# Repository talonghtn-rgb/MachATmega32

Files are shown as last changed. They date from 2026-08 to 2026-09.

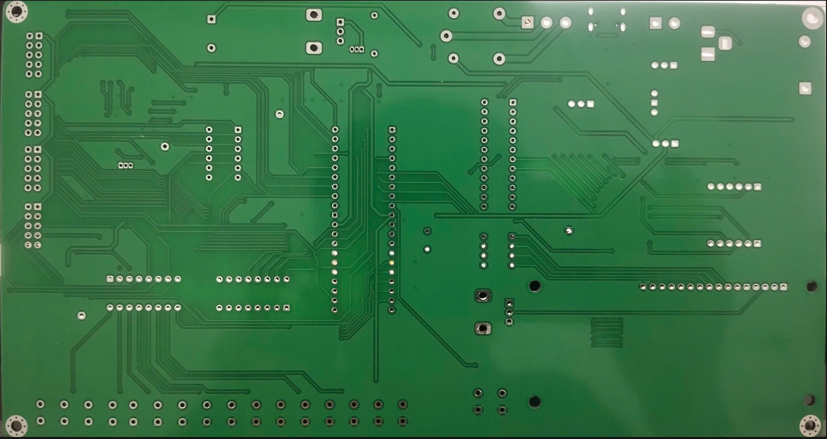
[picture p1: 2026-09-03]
Sp mặt sau.png

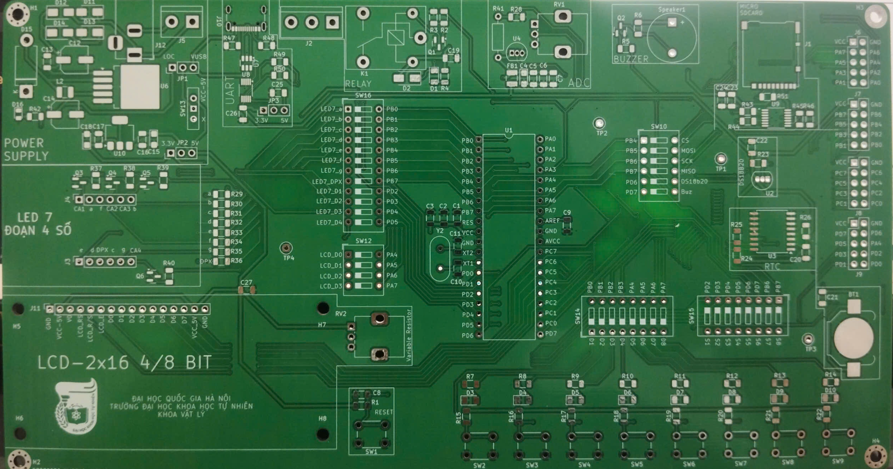
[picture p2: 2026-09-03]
Sp mặt trước.png

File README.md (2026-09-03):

# ATmega32 Embedded Learning Board

<h2 align="center">
  THIẾT KẾ VÀ CHẾ TẠO BO MẠCH LẬP TRÌNH NHÚNG DỰA TRÊN VI ĐIỀU KHIỂN AVR CHO MỤC ĐÍCH GIÁO DỤC
</h2>

<p align="center">
  <b>ATmega32 Embedded Training Board</b>
</p>

---

##  Giới thiệu

Đây là dự án thiết kế và chế tạo **bo mạch học tập lập trình nhúng sử dụng vi điều khiển ATmega32**, được xây dựng nhằm phục vụ việc học tập, thực hành và nghiên cứu các hệ thống nhúng.

Bo mạch tích hợp nhiều ngoại vi phổ biến, giúp sinh viên có thể thực hành lập trình vi điều khiển, giao tiếp với cảm biến, thiết bị hiển thị, bộ nhớ và các chuẩn giao tiếp thông dụng.

Toàn bộ sơ đồ nguyên lý và PCB của bo mạch được thiết kế bằng **KiCad**.

---

##  Mục tiêu

- Thiết kế một bo mạch học tập dựa trên vi điều khiển **ATmega32**.
- Tích hợp các ngoại vi thường sử dụng trong các bài thực hành vi điều khiển.
- Hỗ trợ nhiều chuẩn giao tiếp như UART, I2C, SPI và 1-Wire.
- Thiết kế PCB hoàn chỉnh bằng KiCad.
- Xây dựng nền tảng phần cứng phục vụ các bài thực hành lập trình nhúng.
- Kiểm thử từng chức năng của bo mạch trên phần cứng thực tế.

---

##  Vi điều khiển:  ATmega32

##  Các ngoại vi tích hợp

Bo mạch được thiết kế với các khối chức năng:

| Ngoại vi | Chức năng |
|---|---|
| LCD 16x2 | Hiển thị thông tin |
| LED 7 đoạn 4 số | Hiển thị số |
| LM35 | Đo nhiệt độ |
| DS18B20 | Cảm biến nhiệt độ |
| DS3231 | Đồng hồ thời gian thực |
| Relay | Điều khiển thiết bị |
| Micro SD Card | Lưu trữ dữ liệu |
| LED đơn | Hiển thị trạng thái |
| Button | Nhập tín hiệu số |
| Potentiometer | Tạo tín hiệu analog |
| LDR | Đo cường độ ánh sáng |
| CH340E | Giao tiếp USB-UART |

Các ngoại vi trên được tích hợp nhằm phục vụ nhiều bài thực hành về GPIO, ADC, UART, I2C, SPI, 1-Wire và điều khiển thiết bị.

---

##  Các chuẩn giao tiếp
UART,I2C,SPI,1-Wire

##  Thiết kế bằng KiCad

Project được thiết kế bằng **KiCad 9**.

Các file chính:

```text
ATmega32/
│
├── atmega32.kicad_pro       # KiCad Project
├── atmega32.kicad_sch       # Schematic
├── atmega32.kicad_pcb       # PCB Layout
│
├── aa.kicad_sym             # Custom Symbol Library
│
├── CR1220 SMD.pretty/       # Footprint Library
├── Micro.pretty/            # Footprint Library
├── SN74LVC125APWR.pretty/   # Footprint Library
│
├── fp-lib-table
├── sym-lib-table
└── Logo_hus.png
```

## Hình ảnh sản phẩm trong quá trình làm
## Ghi chú: Hình ảnh ở trên là bản đầu tiên làm, file ở trên đã sửa sau khi test các chức năng sửa những lỗi cho ra bản hoàn chỉnh nhất.

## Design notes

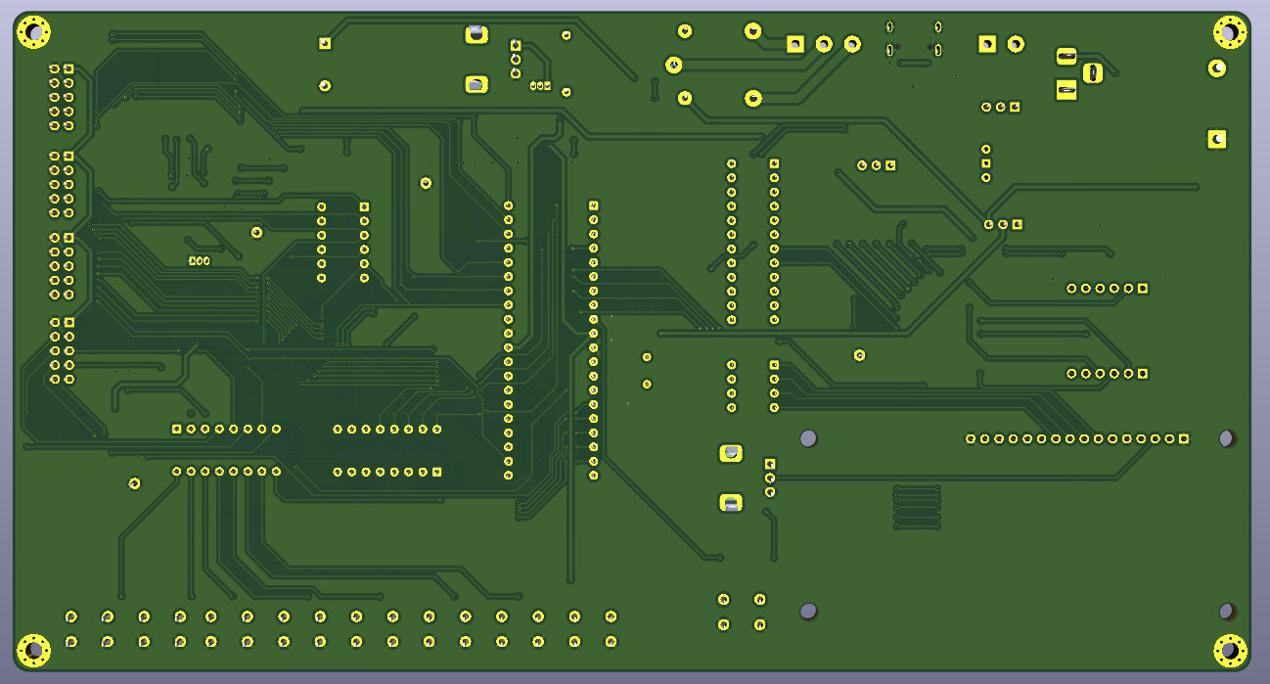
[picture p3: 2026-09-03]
Mach_ban3D_matsau.png

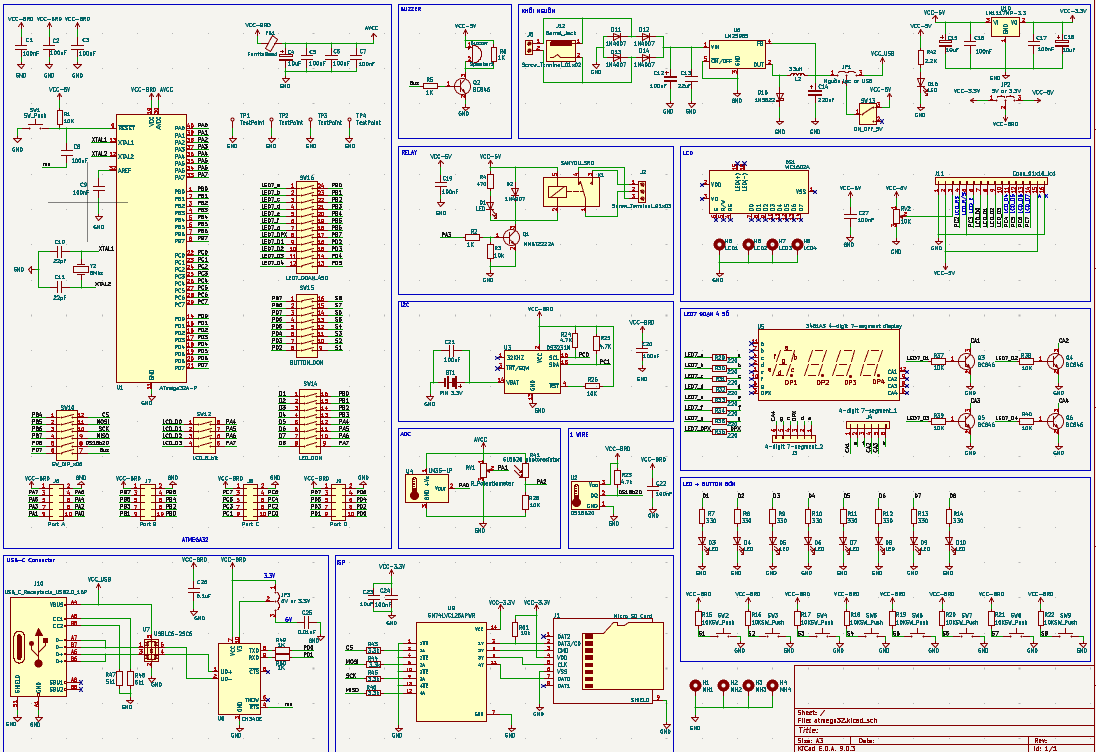
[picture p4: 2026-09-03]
machchinh_sche.png

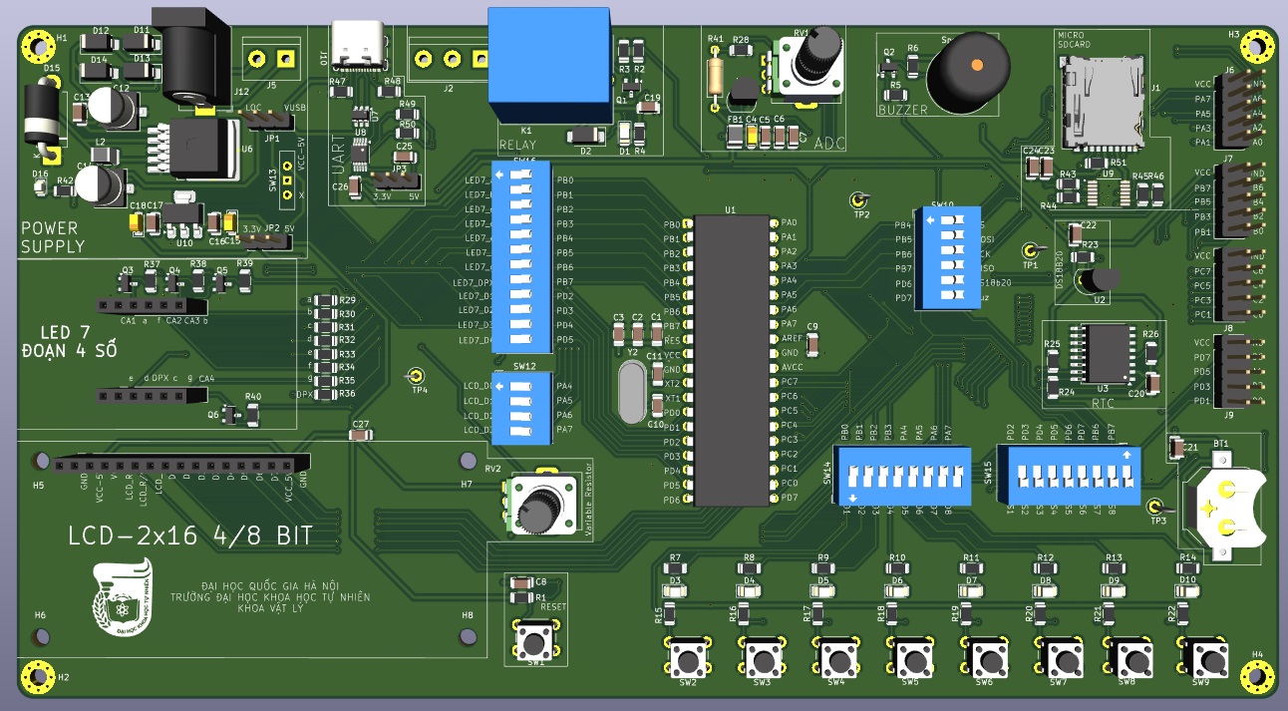
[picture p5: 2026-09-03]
Mach_ban3D_mattruoc.png

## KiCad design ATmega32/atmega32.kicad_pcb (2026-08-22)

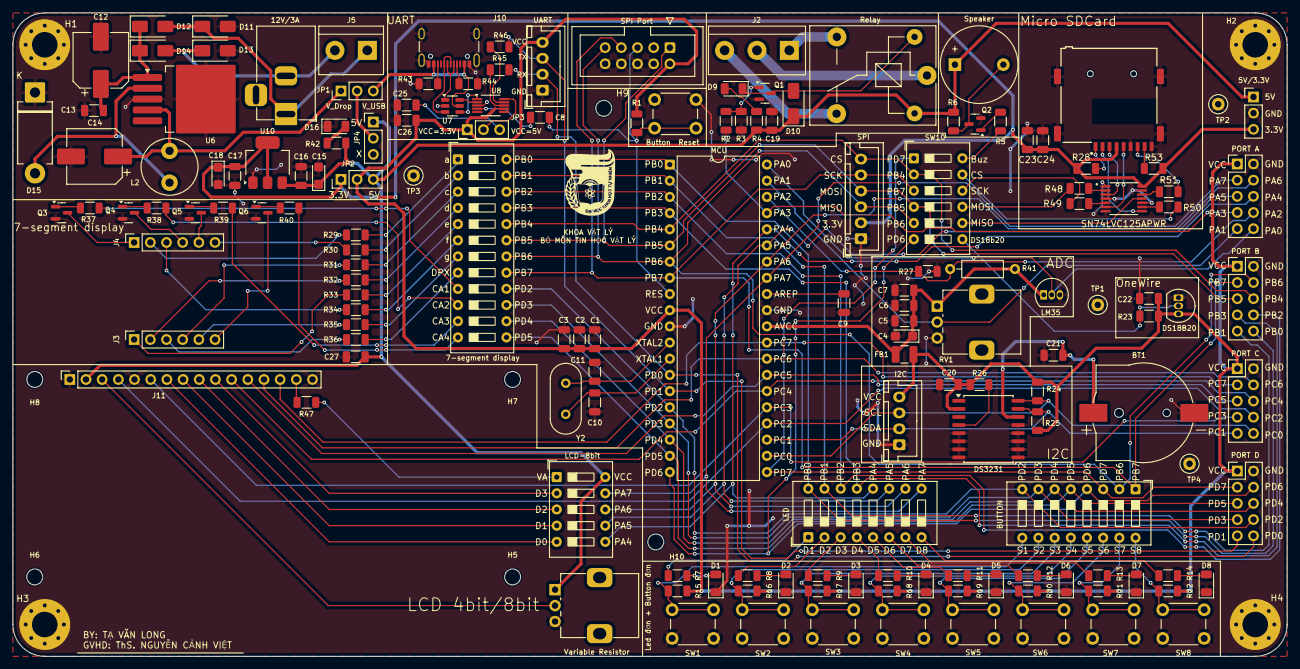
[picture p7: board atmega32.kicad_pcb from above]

Board: 2 copper layers, 200.0 x 101.0 mm, 168 parts (0 on the bottom side), 145 nets.

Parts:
5V/3.3V: 5V/3.3V; PinHeader_1x03_P2.54mm_Vertical
7-segment display: LED7_DOAN_4SO; SW_DIP_SPSTx12_Slide_9.78x32.66mm_W7.62mm_P2.54mm
12V/3A: Barrel_Jack; BarrelJack_Horizontal
 : LOGO
BT1: PIN; BatteryHolder_RSPRO_2378296_1x1220
BUTTON: BUTTON_DON; SW_DIP_SPSTx08_Slide_9.78x22.5mm_W7.62mm_P2.54mm
Button  Reset: SW_Push; SW_PUSH_6mm_H5mm
C1, C2, C3, C5, C6, C7, C8, C9, C16, C17, C19, C20, C21, C22, C24, C26, C27: 100nF; C_1206_3216Metric
C4, C15, C18: 10uF; CP_EIA-3216-18_Kemet-A
C10, C11: 22pF; C_1206_3216Metric
C12: 440uF/35V; CP_Elec_8x10.5
C13: 1000nF; C_1206_3216Metric
C14: 330uF/35V; CP_Elec_8x10.5
C23: 10uF; C_1206_3216Metric
C25: 10nF; C_1206_3216Metric
D1, D2, D3, D4, D5, D6, D7, D8, D9, D16: LED; LED_1206_3216Metric
D10, D11, D12, D13, D14: 1N4007; D_SMA
D15: 1N5822; D_DO-201AD_P12.70mm_Horizontal
DS18B20: DS18B20; TO-92_Inline
DS3231: DS3231M; SOIC-16W_7.5x10.3mm_P1.27mm
FB1: FerriteBead; L_1210_3225Metric
H1: MH1; MountingHole_4mm_Pad_Via
H2: MH2; MountingHole_4mm_Pad_Via
H3: MH3; MountingHole_4mm_Pad_Via
H4: MH4; MountingHole_4mm_Pad_Via
H5: LCD1; MountingHole_2.5mm
H6: LCD2; MountingHole_2.5mm
H7: LCD3; MountingHole_2.5mm
H8: LCD4; MountingHole_2.5mm
H9: MH5; MountingHole_2.5mm
H10: MH6; MountingHole_2.5mm
I2C: SCL/SDA; JST_XH_B4B-XH-A_1x04_P2.50mm_Vertical
J1: Micro_SD_Card; GCT_MEM2075
J2: Screw_Terminal_01x03; TerminalBlock_bornier-3_P5.08mm
J3: 4-digit 7-segment_2; PinSocket_1x06_P2.54mm_Vertical
J4: 4-digit 7-segment_1; PinSocket_1x06_P2.54mm_Vertical
J5: Screw_Terminal_01x02; TerminalBlock_bornier-2_P5.08mm
J10: USB_C_Receptacle_USB2.0_16P; USB_C_Receptacle_GCT_USB4105-xx-A_16P_TopMnt_Horizontal
J11: Conn_01x16_lcd; PinSocket_1x16_P2.54mm_Vertical
JP1: Nguồn lọc or USB; PinHeader_1x03_P2.54mm_Vertical
JP2, JP3: 5V or 3.3V; PinHeader_1x03_P2.54mm_Vertical
JP4: 5V or x; PinHeader_1x03_P2.54mm_Vertical
L2: 33uH; L_Radial_D8.7mm_P5.00mm_Fastron_07HCP
LCD-8bit: SW_LCD_8bit; SW_DIP_SPSTx05_Slide_9.78x14.88mm_W7.62mm_P2.54mm
LED: LED_DON; SW_DIP_SPSTx08_Slide_9.78x22.5mm_W7.62mm_P2.54mm
LM35: LM35-LP; TO-92_Inline
MCU: ATmega32A-P; DIP-40_W15.24mm
PORT A: Port A; PinHeader_2x05_P2.54mm_Vertical
PORT B: Port B; PinHeader_2x05_P2.54mm_Vertical
PORT C: Port C; PinHeader_2x05_P2.54mm_Vertical
PORT D: Port D; PinHeader_2x05_P2.54mm_Vertical
Q1: MMBT2222A; SOT-23
Q2, Q3, Q4, Q5, Q6: BC846; SOT-23
R1, R15, R16, R17, R18, R19, R20, R21, R22, R26, R27, R37, R38, R39, R40: 10K; R_1206_3216Metric
R2, R5, R6, R45, R46: 1K; R_1206_3216Metric
R3: 10k; R_1206_3216Metric
R4: 470; R_1206_3216Metric
R7, R8, R9, R10, R11, R12, R13, R14: 330; R_1206_3216Metric
R23: 4.7k; R_1206_3216Metric
R24, R25, R28, R53: 4.7K; R_1206_3216Metric
R29, R30, R31, R32, R33, R34, R35, R36, R47: 220; R_1206_3216Metric
R41: GL5528 photoresistor; R_Axial_DIN0207_L6.3mm_D2.5mm_P10.16mm_Horizontal
R42: 2.2K; R_1206_3216Metric
R43, R44: 5k1; R_1206_3216Metric
R48, R49, R50, R51: 3.3K; R_1206_3216Metric
RV1: R_Potentiometer; Potentiometer_Alps_RK09K_Single_Vertical
Relay: SANYOU_SRD; Relay_SPDT_SANYOU_SRD_Series_Form_C
SN74LVC125APWR: SN74LVC125APWR; SOP65P640X120-14N
SPI: SPI; JST_XH_B6B-XH-A_1x06_P2.50mm_Vertical
SPI Port: AVR-ISP-10; IDC-Header_2x05_P2.54mm_Vertical
SW1, SW2, SW3, SW4, SW5, SW6, SW7, SW8: SW_Push; SW_PUSH_6mm_H5mm
SW10: SW_DIP_x06; SW_DIP_SPSTx06_Slide_9.78x17.42mm_W7.62mm_P2.54mm
Speaker: Buzzer; Buzzer_12x9.5RM7.6
TP1, TP2, TP3, TP4: TestPoint; TestPoint_Loop_D2.50mm_Drill1.0mm
U6: LM2596S-ADJ; TO-263-5_TabPin3
U7: USBLC6-2SC6; SOT-23-6
U8: CH340E; MSOP-10_3x3mm_P0.5mm
U10: LM1117MP-3.3; SOT-223-3_TabPin2
UART: TX/RX; JST_XH_B4B-XH-A_1x04_P2.50mm_Vertical
Variable Resistor: 10K; Potentiometer_Alps_RK09K_Single_Vertical
Y2: 8Mhz; Crystal_HC49-U_Vertical

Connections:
/Buz: R5.1, SW10.12
/CA1: J4.1, Q3.3 (C)
/CA2: J4.4, Q4.3 (C)
/CA3: J4.5, Q5.3 (C)
/CA4: J3.6, Q6.3 (C)
/CD: J1.2 (DAT3/CD), SN74LVC125APWR.8 (3Y)
/CLK: J1.5 (CLK), SN74LVC125APWR.6 (2Y)
/CMD: J1.3 (CMD), SN74LVC125APWR.3 (1Y)
/CS: R50.2, SW10.11
/D0: J1.7 (DAT0), R51.2
/D1: LED.1, R7.2
/D2: LED.2, R8.2
/D3: LED.3, R9.2
/D4: LED.4, R10.2
/D5: LED.5, R11.2
/D6: LED.6, R12.2
/D7: LED.7, R13.2
/D8: LED.8, R14.2
/DPX: J3.3, R36.2
/DS18b20: DS18B20.2 (DQ), R23.1, SW10.7
/LCD_D0: J11.7, LCD-8bit.5
/LCD_D1: J11.8, LCD-8bit.4
/LCD_D2: J11.9, LCD-8bit.3
/LCD_D3: J11.10, LCD-8bit.2
/LED7_D1: 7-segment display.9, R37.1
/LED7_D2: 7-segment display.10, R38.1
/LED7_D3: 7-segment display.11, R39.1
/LED7_D4: 7-segment display.12, R40.1
/LED7_DPX: 7-segment display.8, R36.1
/LED7_a: 7-segment display.1, R29.1
/LED7_b: 7-segment display.2, R30.1
/LED7_c: 7-segment display.3, R31.1
/LED7_d: 7-segment display.4, R32.1
/LED7_e: 7-segment display.5, R33.1
/LED7_f: 7-segment display.6, R34.1
/LED7_g: 7-segment display.7, R35.1
/MISO: SN74LVC125APWR.11 (4Y), SW10.8
/MOSI: R48.2, SW10.9
/PA0: LM35.2 (V_{OUT}), MCU.40 (PA0), PORT A.10
/PA1: MCU.39 (PA1), PORT A.9, RV1.2
/PA2: MCU.38 (PA2), PORT A.8, R27.1, R41.2
/PA3: MCU.37 (PA3), PORT A.7, R2.1
/PA4: LCD-8bit.6, LED.12, MCU.36 (PA4), PORT A.6
/PA5: LCD-8bit.7, LED.11, MCU.35 (PA5), PORT A.5
/PA6: LCD-8bit.8, LED.10, MCU.34 (PA6), PORT A.4
/PA7: LCD-8bit.9, LED.9, MCU.33 (PA7), PORT A.3
/PB0: 7-segment display.24, LED.16, MCU.1 (PB0), PORT B.10
/PB1: 7-segment display.23, LED.15, MCU.2 (PB1), PORT B.9
/PB2: 7-segment display.22, LED.14, MCU.3 (PB2), PORT B.8
/PB3: 7-segment display.21, LED.13, MCU.4 (PB3), PORT B.7
/PB4: 7-segment display.20, MCU.5 (PB4), PORT B.6, SPI.6, SW10.2
/PB5: 7-segment display.19, MCU.6 (PB5), PORT B.5, SPI.4, SPI Port.1 (MOSI), SW10.4
/PB6: 7-segment display.18, BUTTON.2, MCU.7 (PB6), PORT B.4, SPI.3, SPI Port.9 (MISO), SW10.5
/PB7: 7-segment display.17, BUTTON.1, MCU.8 (PB7), PORT B.3, SPI.5, SPI Port.7 (SCK), SW10.3
/PC0: DS3231.16 (SCL), I2C.3, MCU.22 (PC0), PORT C.10, R24.1
/PC1: DS3231.15 (SDA), I2C.2, MCU.23 (PC1), PORT C.9, R25.1
/PC2: J11.4, MCU.24 (PC2), PORT C.8
/PC3: J11.6, MCU.25 (PC3), PORT C.7
/PC4: J11.11, MCU.26 (PC4), PORT C.6
/PC5: J11.12, MCU.27 (PC5), PORT C.5
/PC6: J11.13, MCU.28 (PC6), PORT C.4
/PC7: J11.14, MCU.29 (PC7), PORT C.3
/PD0: MCU.14 (PD0), PORT D.10, R45.2, UART.2
/PD1: MCU.15 (PD1), PORT D.9, R46.2, UART.3
/PD2: 7-segment display.16, BUTTON.8, MCU.16 (PD2), PORT D.8
/PD3: 7-segment display.15, BUTTON.7, MCU.17 (PD3), PORT D.7
/PD4: 7-segment display.14, BUTTON.6, MCU.18 (PD4), PORT D.6
/PD5: 7-segment display.13, BUTTON.5, MCU.19 (PD5), PORT D.5
/PD6: BUTTON.4, MCU.20 (PD6), PORT D.4, SW10.6
/PD7: BUTTON.3, MCU.21 (PD7), PORT D.3, SW10.1
/S1: BUTTON.9, R15.1, SW1.1
/S2: BUTTON.10, R16.1, SW2.1
/S3: BUTTON.11, R17.1, SW3.1
/S4: BUTTON.12, R18.1, SW4.1
/S5: BUTTON.13, R19.1, SW5.1
/S6: BUTTON.14, R20.1, SW6.1
/S7: BUTTON.15, R21.1, SW7.1
/S8: BUTTON.16, R22.1, SW8.1
/SCK: R49.2, SW10.10
/VA: LCD-8bit.1, R47.1
/a: J4.2, R29.2
/b: J4.6, R30.2
/c: J3.4, R31.2
/d: J3.2, R32.2
/e: J3.1, R33.2
/f: J4.3, R34.2
/g: J3.5, R35.2
/reset: Button Reset.2, C8.2, MCU.9 (~RESET), R1.2, SPI Port.5 (~RST)
AVCC: C4.1, C5.1, C6.1, C7.1, FB1.2, LM35.1 (+V_{S}), MCU.30 (AVCC), R41.1, RV1.1
GND: 5V/3.3V.2, BT1.2 (-), Button Reset.1, C1.1, C2.1, C3.1, C4.2, C5.2, C6.2, C7.2, C9.1, C10.1, C11.1, C12.2, C13.1, C14.2, C15.2, C16.1, C17.2, C18.2, C19.1, C20.1, C21.1, C22.2, C23.2, C24.2, C25.2, C26.2, C27.2, D1.1 (K), D2.1 (K), D3.1 (K), D4.1 (K), D5.1 (K), D6.1 (K), D7.1 (K), D8.1 (K), D11.2 (A), D13.2 (A), D15.1 (K), D16.1 (K), DS18B20.1 (GND), DS3231.5 (GND), DS3231.6 (GND), DS3231.7 (GND), DS3231.8 (GND), DS3231.9 (GND), DS3231.10 (GND), DS3231.11 (GND), DS3231.12 (GND), DS3231.13 (GND), H1.1, H2.1, H3.1, H4.1, I2C.1, J1.6 (VSS), J1.9 (SHIELD), J10.A1 (GND), J10.A12 (GND), J10.B1 (GND), J10.B12 (GND), J10.S1 (SHIELD), J11.1, J11.5, J11.16, LM35.3 (GND), MCU.11 (GND), MCU.31 (GND), PORT A.2, PORT B.2, PORT C.2, PORT D.2, Q1.2 (E), Q2.2 (E), Q3.2 (E), Q4.2 (E), Q5.2 (E), Q6.2 (E), R3.2, R27.2, R43.2, R44.2, RV1.3, SN74LVC125APWR.1 (1~OE), SN74LVC125APWR.4 (2~OE), SN74LVC125APWR.7 (GND), SN74LVC125APWR.10 (3~OE), SN74LVC125APWR.13 (4~OE), SPI.1, SPI Port.4 (GND), SPI Port.6 (GND), SPI Port.8 (GND), SPI Port.10 (GND), SW1.2, SW2.2, SW3.2, SW4.2, SW5.2, SW6.2, SW7.2, SW8.2, TP1.1, TP2.1, TP3.1, TP4.1, U6.3 (GND), U7.2 (GND), U8.3 (GND), U10.1 (GND), UART.1, Variable Resistor.3
unnamed: BT1.1 (+), C21.2, DS3231.14 (VBAT)
unnamed: D1.2 (A), R7.1
unnamed: D2.2 (A), R8.1
unnamed: D3.2 (A), R9.1
unnamed: D4.2 (A), R10.1
unnamed: D5.2 (A), R11.1
unnamed: D6.2 (A), R12.1
unnamed: D7.2 (A), R13.1
unnamed: D8.2 (A), R14.1
unnamed: D9.2 (A), R4.2
unnamed: D9.1 (K), D10.2 (A), Q1.3 (C), Relay.2
unnamed: 12V/3A.1, D11.1 (K), D12.2 (A), J5.1
unnamed: C12.1, C13.2, D12.1 (K), D14.1 (K), U6.1 (VIN)
unnamed: 12V/3A.2, D13.1 (K), D14.2 (A), J5.2
unnamed: D15.2 (A), L2.1, U6.2 (OUT)
unnamed: D16.2 (A), R42.1
unnamed: J1.8 (DAT1), R53.2
unnamed: J1.1 (DAT2), R28.2
unnamed: J2.1, Relay.3
unnamed: J2.2, Relay.1
unnamed: J2.3, Relay.4
unnamed: J10.A5 (CC1), R44.1
unnamed: J10.B5 (CC2), R43.1
unnamed: J10.A6 (D+), J10.B6 (D+), U7.3 (I/O2)
unnamed: J10.A7 (D-), J10.B7 (D-), U7.1 (I/O1)
unnamed: J11.3, Variable Resistor.2
unnamed: J11.15, R47.2
unnamed: C14.1, JP1.1 (A), L2.2, U6.4 (FB)
unnamed: JP1.2 (C), JP4.2 (C)
unnamed: C25.1, JP3.3 (B)
unnamed: JP3.2 (C), U8.10 (V3)
unnamed: Q1.1 (B), R2.2, R3.1
unnamed: Q2.1 (B), R5.2
unnamed: Q2.3 (C), R6.1, Speaker.2 (-)
unnamed: Q3.1 (B), R37.2
unnamed: Q4.1 (B), R38.2
unnamed: Q5.1 (B), R39.2
unnamed: Q6.1 (B), R40.2
unnamed: C9.2, MCU.32 (AREF)
unnamed: C10.2, MCU.13 (XTAL1), Y2.2
unnamed: C11.2, MCU.12 (XTAL2), Y2.1
unnamed: DS3231.4 (~RST), R26.2
unnamed: R46.1, U8.9 (RXD)
unnamed: R45.1, U8.8 (TXD)
unnamed: U7.4 (I/O2), U8.1 (UD+)
unnamed: U7.6 (I/O1), U8.2 (UD-)
unnamed: C8.1, U8.4 (~RTS)
unnamed: R48.1, SN74LVC125APWR.2 (1A)
unnamed: R49.1, SN74LVC125APWR.5 (2A)
unnamed: R50.1, SN74LVC125APWR.9 (3A)
unnamed: R51.1, SN74LVC125APWR.12 (4A)
VCC-3.3V: 5V/3.3V.3, C17.1, C18.1, C23.1, C24.1, J1.4 (VDD), JP2.1 (A), R28.1, R53.1, SN74LVC125APWR.14 (VCC), SPI.2, U10.2 (VO)
VCC-5V: 5V/3.3V.1, C15.1, C16.2, C19.2, C27.1, D10.1 (K), J11.2, JP2.3 (B), JP4.1 (A), LCD-8bit.10, R4.1, R6.2, R42.2, Relay.5, Speaker.1 (+), U10.3 (VI), Variable Resistor.1
VCC-BRD: C1.2, C2.2, C3.2, C20.2, C22.1, C26.1, DS18B20.3 (V_{DD}), DS3231.2 (VCC), FB1.1, I2C.4, JP2.2 (C), JP3.1 (A), MCU.10 (VCC), PORT A.1, PORT B.1, PORT C.1, PORT D.1, R1.1, R15.2, R16.2, R17.2, R18.2, R19.2, R20.2, R21.2, R22.2, R23.2, R24.2, R25.2, R26.1, SPI Port.2 (VCC), U8.7 (VCC), UART.4
VCC_USB: J10.A4 (VBUS), J10.A9 (VBUS), J10.B4 (VBUS), J10.B9 (VBUS), JP1.3 (B), U7.5 (VBUS)
